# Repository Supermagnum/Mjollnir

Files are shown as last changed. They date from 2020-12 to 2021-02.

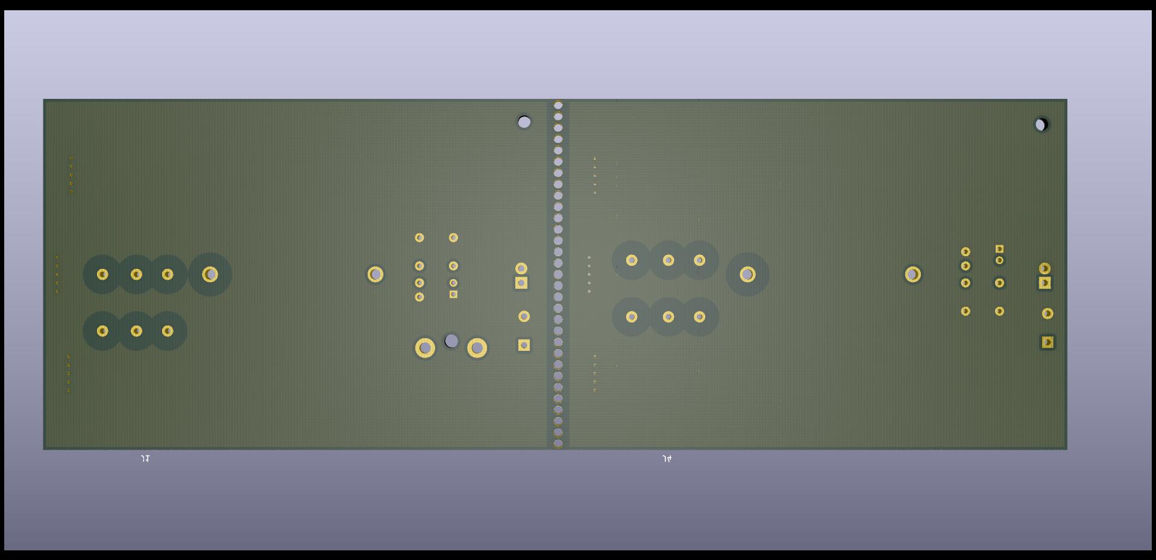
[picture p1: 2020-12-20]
10A-Bias-T-back.jpg

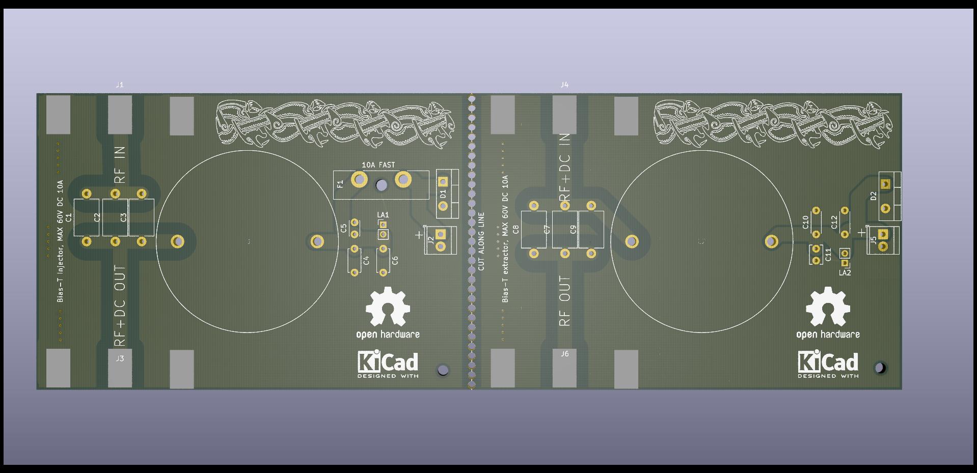
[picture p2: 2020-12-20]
10A-Bias-T-front.jpg

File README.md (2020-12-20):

# Mjollnir
A Bias-T cicuit board that handles 10A 60 volts DC.

Frequency range: 160 meters to 70 cm.

It has reverse polarity protection and protection from voltage spikes generated by relays.

The circuit boards are made so they actually are two boards, one injector and one extractor board.

They are easy to separate, as there are a line of closely spaced holes made for that exact purpose.

Voltage indicators should be LED with a proper non inductive current limiting resistor.

Schematic diagram and part numbers:

https://github.com/Supermagnum/Mjollnir/blob/main/10A-Bias-T-schem-BOM.pdf

Picture of the PCB :

https://github.com/Supermagnum/Mjollnir/blob/main/10A-Bias-T-front.jpg

PCB's:

https://aisler.net/p/ATXVEJSE

Bill of materials:

https://github.com/Supermagnum/Mjollnir/blob/main/bom.txt

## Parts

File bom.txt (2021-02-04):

Quoted (19 components)
	J6 	Conn_Coaxial 	172323 	Amphenol RF 	n 		€9.30
	J4 	Conn_Coaxial 	172323 	Amphenol RF 	n 		€9.30
	J3 	Conn_Coaxial 	172323 	Amphenol RF 	n 		€9.30
	J1 	Conn_Coaxial 	172323 	Amphenol RF 	n 		€9.30
	C4 	1uF 	C330C105K1R5TA 	KEMET 	c disc d4.7mm w2.5mm p5.00mm 		€1.38
	C10 	1uF 	C330C105K1R5TA 	KEMET 	c disc d4.3mm w1.9mm p5.00mm 		€1.38
	C6 	0.1uF 	C330C104K2R5TA7301 	KEMET 	c disc d4.7mm w2.5mm p5.00mm 		€0.35
	C12 	0.1uF 	C330C104K2R5TA7301 	KEMET 	c disc d4.3mm w1.9mm p5.00mm 		€0.35
	C5 	100uF 	C315C101K2R5TA 	KEMET 	c disc d3.0mm w2.0mm p2.50mm 		€0.29
	C11 	100uF 	C315C101K2R5TA 	KEMET 	c disc d3.8mm w2.6mm p2.50mm 		€0.29
	D2 	D 	STPS10L60D 	STMicroelectronics 	to-220-2 vertical 		€1.07
	D1 	D 	STPS10L60D 	STMicroelectronics 	to-220-2 vertical 		€1.07
	F1 	10A 	178.6764.0001 	Littelfuse Inc. 	fuseholder blade ato littelfuse pudenz 2 pin 		€2.26
	10A fast blow automotive fuse, blade type.
	€7.18
	inductors is 2X Amidon FT140-42 with 11 turns of #16 AWG Ø1.3mm magnet wire.
	C1,C2,C3,C7,C8,C9  564R2DF0D22 0.0022uF 2KV DC
	LA1 	Lamp 	FL1M-8SW-1-G24V 	Mallory Sonalert 
	LA1 	FL1M-8SW-1-G24V 	FL1M-8SW-1-G24V 			€3.01

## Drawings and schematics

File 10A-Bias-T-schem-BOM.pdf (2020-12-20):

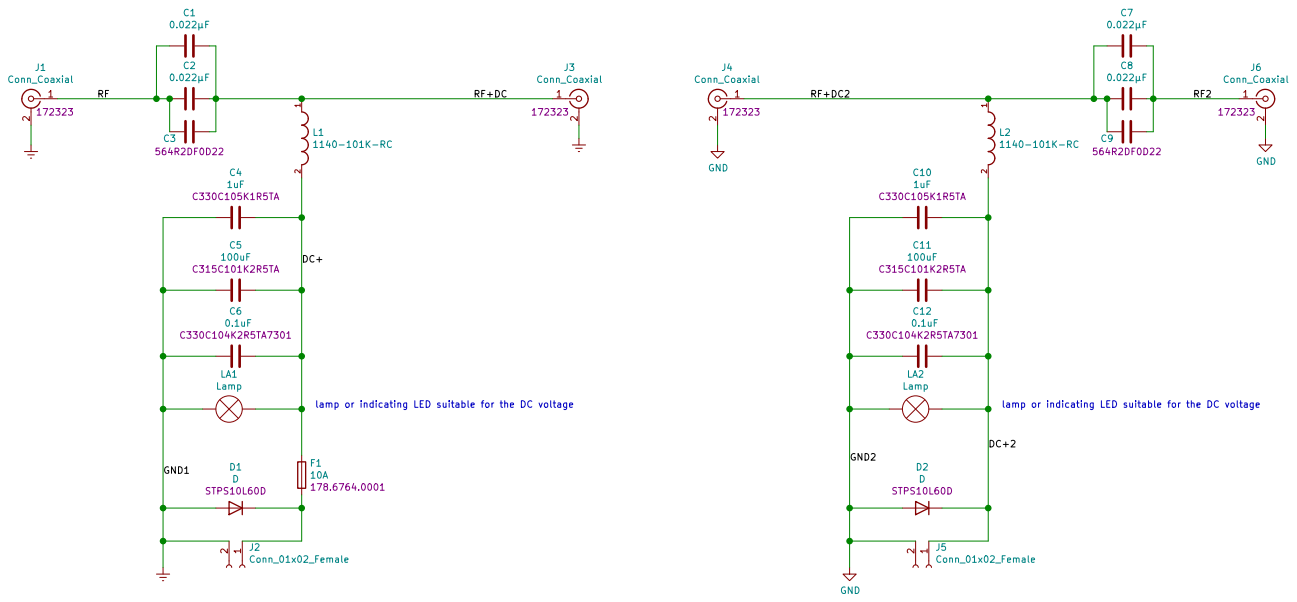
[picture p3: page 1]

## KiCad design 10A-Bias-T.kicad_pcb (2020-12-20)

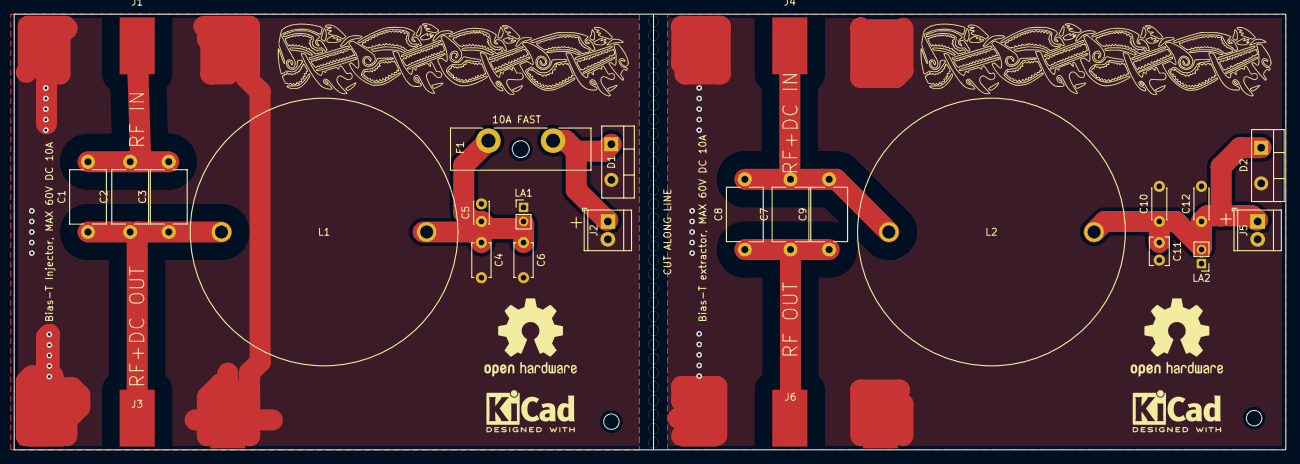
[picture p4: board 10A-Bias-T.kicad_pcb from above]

Board: 2 copper layers, 181.0 x 62.0 mm, 25 parts (0 on the bottom side), 9 nets.

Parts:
C1, C2, C3, C7, C8, C9: 0.022µF; C_Disc_D7.5mm_W5.0mm_P10.00mm
C4: 1uF; C_Disc_D4.7mm_W2.5mm_P5.00mm
C5: 100uF; C_Disc_D3.0mm_W2.0mm_P2.50mm
C6: 0.1uF; C_Disc_D4.7mm_W2.5mm_P5.00mm
C10: 1uF; C_Disc_D4.3mm_W1.9mm_P5.00mm
C11: 100uF; C_Disc_D3.8mm_W2.6mm_P2.50mm
C12: 0.1uF; C_Disc_D4.3mm_W1.9mm_P5.00mm
D1, D2: D; TO-220-2_Vertical
F1: 10A; Fuseholder_Blade_ATO_Littelfuse_Pudenz_2_Pin
J1, J3, J4, J6: Conn_Coaxial; N
J2, J5: Conn_01x02_Female; TerminalBlock_TE_282834-2_1x02_P2.54mm_Horizontal
L1, L2: 1140-101K-RC; INDRD2921W163D3810H2616P
LA1, LA2: Lamp; PinHeader_1x02_P2.00mm_Vertical

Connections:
/DC+: C4.1, C5.1, C6.1, F1.1, L1.2, LA1.2
/DC+2: C10.1, C11.1, C12.1, D2.1, J5.1, L2.2, LA2.2
/RF: C1.2, C2.2, C3.2, J1.1
/RF2: C7.1, C8.1, C9.1, J6.1
/RF+DC: C1.1, C2.1, C3.1, J3.1, L1.1
/RF+DC2: C7.2, C8.2, C9.2, J4.1, L2.1
Earth: C4.2, C5.2, C6.2, D1.2, J1.2, J1.3, J2.2, J3.2, J3.3, LA1.1
GND: C10.2, C11.2, C12.2, D2.2, J4.2, J4.3, J5.2, J6.2, J6.3, LA2.1
unnamed: D1.1, F1.2, J2.1

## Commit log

2020-10-07 Add files via upload
    Added gerber files
    [10A-Bias-T-B_Cu.gbr, 10A-Bias-T-B_Mask.gbr, 10A-Bias-T-B_Paste.gbr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]
2020-10-07 Add files via upload
    added misc files.
    [10A-Bias-T.kicad_pcb, 10A-Bias-T.sch]
2020-10-07 added bom.
2020-10-07 Add files via upload
    added BOMS
    [10A-Bias-T-BOM.csv, 10A-Bias-T-BOM.ods]
2020-10-11 Add files via upload
    updates
    [10A-Bias-T-B_Cu.gbr, 10A-Bias-T-B_Mask.gbr, 10A-Bias-T-B_Paste.gbr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]
2020-12-20 Add files via upload
    updated gerbers
    [10A-Bias-T-B_Cu.gbr, 10A-Bias-T-B_Mask.gbr, 10A-Bias-T-B_Paste.gbr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]
2020-12-20 Add files via upload
    updated
    [10A-Bias-T.kicad_pcb]
